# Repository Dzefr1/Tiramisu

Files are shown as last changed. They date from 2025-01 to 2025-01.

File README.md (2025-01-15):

# Tiramisu
Budget and rigid microphone stand costing only around 8$ (cost of plastic) considering you have a donor Tertial lamp.

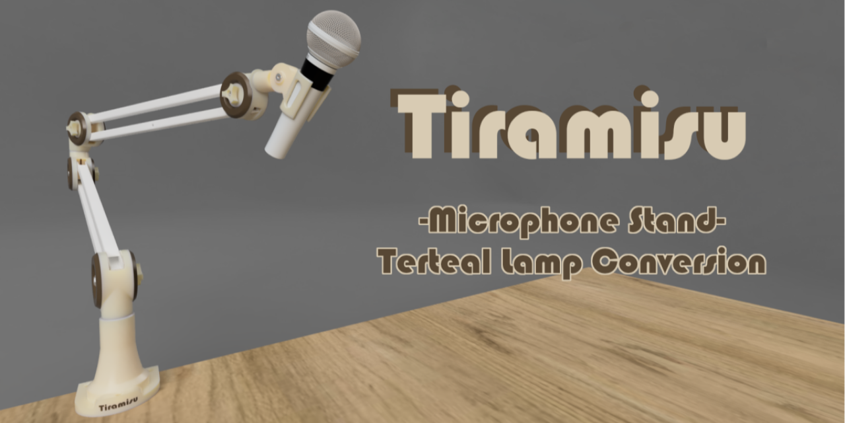
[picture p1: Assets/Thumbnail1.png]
Thumbnail


## Features

Main feature of this design is that it adds two  joints with 360 angle of movement, other also notable features are:
* Larger joint grip area - Additional hole for tightening screw in the middle of the joint, gripping walls of the extrusions more effectively than Tertial's design
* Low amount of materials - Other that filament only additional hardware needed for the conversion are M4 screws (or M4 threaded rod)
* Voron 0 friendly
> Original springs can be used if desired, cap's that hold springs are mountable on tightening screw hole, however additional 35mm M4 rod will be required.

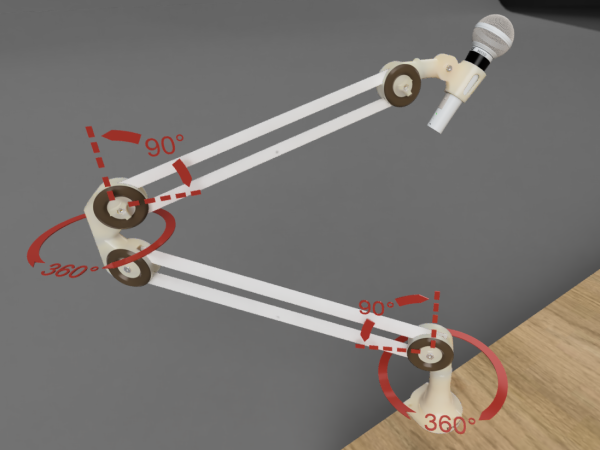
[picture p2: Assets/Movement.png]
movement


## 3D Printing

Most important thing is to **print joints vertically** with 100% infill,
Tested and recommended material is PETG.

### Failures

First few prints of the joints broke after tightening however, part printed vertically was still able to be tightened.
> [!WARNING]  
> If you print with infill less than 100% joints may break when tightening,
> Print settings used on these parts are ABS+ 40% Cubic Infill.
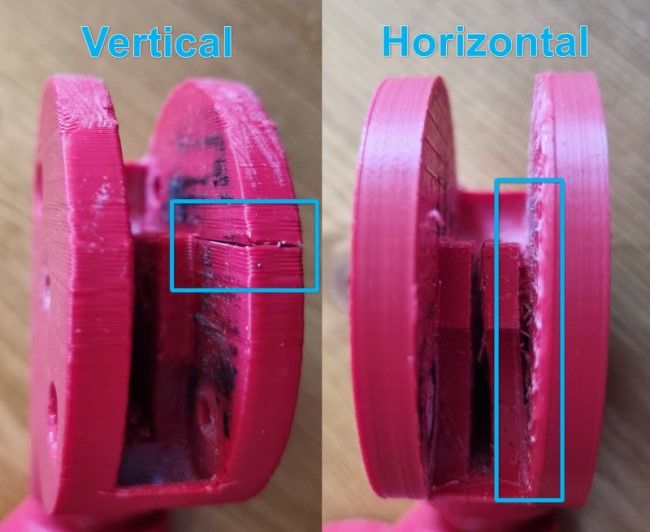
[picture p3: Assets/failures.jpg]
Failures


## Requirements/Part list

* IKEA's Terteal Lamp
* M4 - 28mm Screws x4
* Plastic ~260g (PETG recommended)
* Grease (for rotating joints)

Optional:

* M3 - 8mm or larger (for securing 2nd and 3rd joint)

## Assembly

Build process should be quite self explanatory so I will write down only important notes.

Additional plugs (Plug_Full) should be printed and inserted in extrusions (rods) to make them stiffer,
you can **re-use 4 original cable routing plugs** or print them as well (Plug_Hollow).

Tolerances on joints are TIGHT and that's by design, sanding of round 360 degree joints is required to adjust fit and grease is only used on **1st_Joint** and **3rd_Joint**.

<ins>When assembly is completed all joints need to be tightened to minimize side tilt.<ins>

## Acknowledgments

Inspiration:
* [Rode PSA1](https://rode.com/en-us/accessories/stands-bars/psa1) - Joint Tightening
* [Elgato Wave Mic Arm LP](https://www.elgato.com/us/en/p/wave-mic-arm-lp) - Low Profile

Resources:
* [Parts from Terteal lamp](https://grabcad.com/library/ikea-tertial-2) by: Isabella Grebacken

For rendering:
* [Microphone Holder](https://www.printables.com/model/159430-microphone-holder-for-mic-stand) by: LilMekey
* [Microphone 3D Model](https://grabcad.com/library/shure-microphone-1) by: Keith Moore

## Support 

Like this and want more?

<a href="https://buymeacoffee.com/veljkot6r" target="_blank">Buy Me A Coffee</a>

## License


This work is licensed under CC BY-SA 4.0

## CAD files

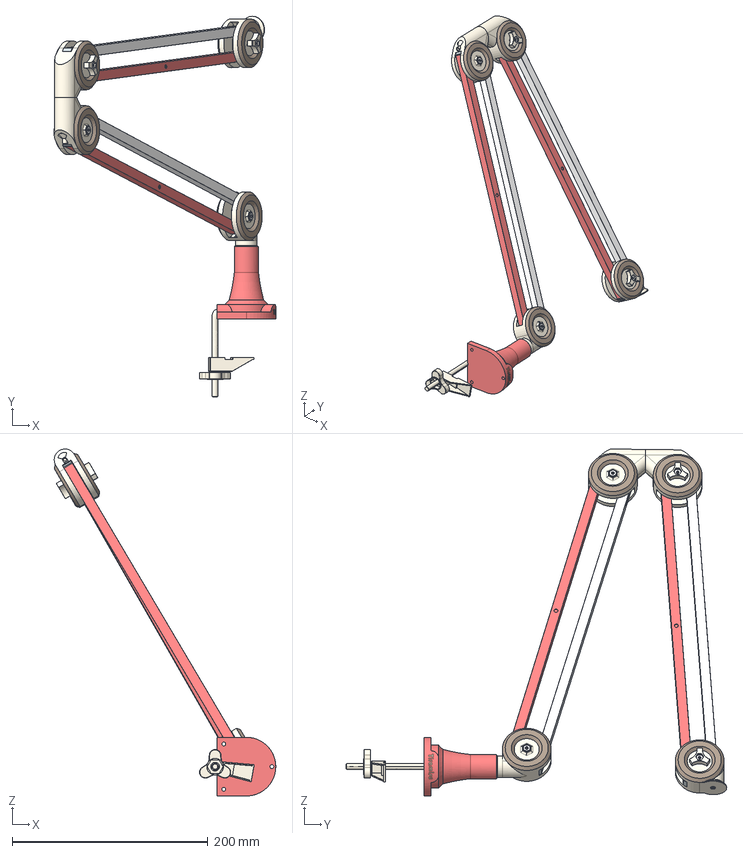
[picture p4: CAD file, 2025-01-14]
3D-Models/Tiramisu_Assembly.step
226.5 x 389.0 x 354.7 mm
1st_Joint
19 Extrusion x 2
19(2) Extrusion x 2
90Deg_2nd_Joint_wSecureScrew
90Deg_3rd_Joint
90Deg_Mic_Mount
28 Base bar
31 Flower knob
30 Security cap
Joint_Cap x 8
24 Triangular knob x 4
14 3mm nut_2_stp x 8
26.2 Cap x 4
26.2 Cap_1 x 4

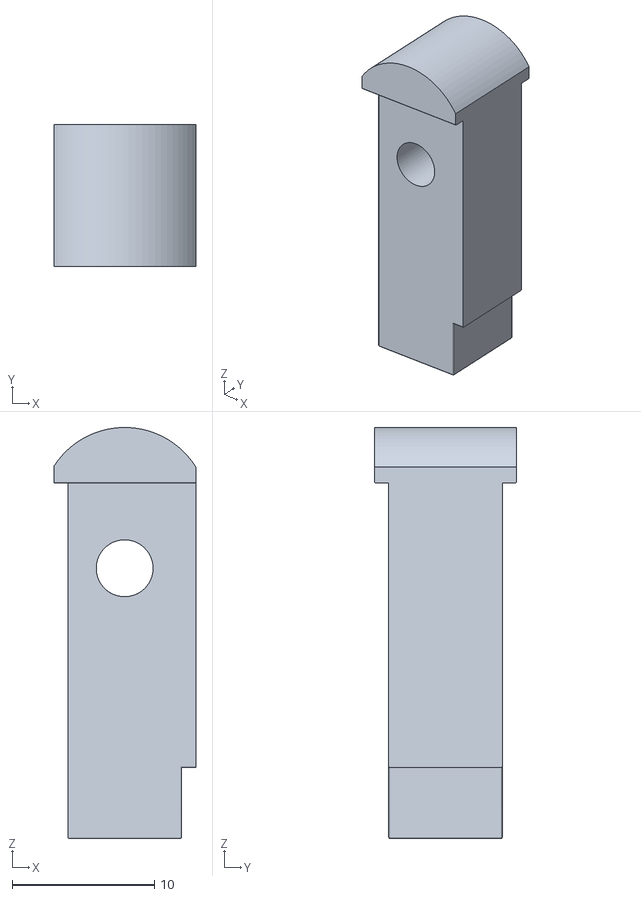
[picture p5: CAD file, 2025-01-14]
3D-Models/Plug_Full.stl
9.95 x 10.0 x 28.9

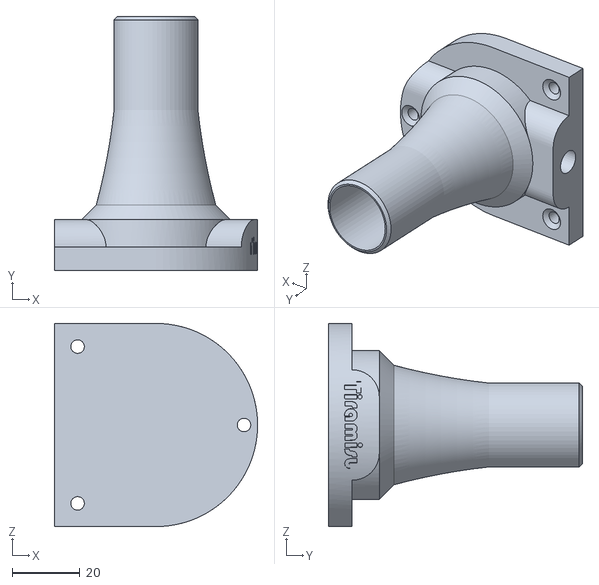
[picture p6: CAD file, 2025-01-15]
3D-Models/Base.stl
60.0 x 75.0 x 60.0

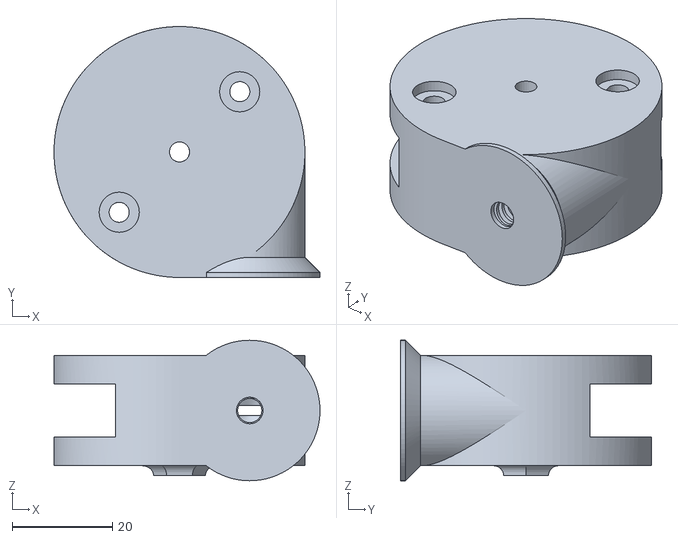
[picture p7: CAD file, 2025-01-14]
3D-Models/Mic_Mount_Variant2.stl
53.0 x 50.0 x 28.0

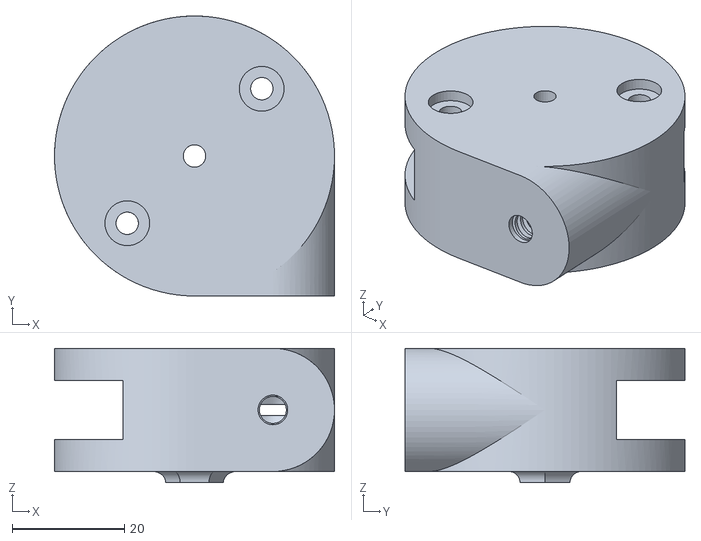
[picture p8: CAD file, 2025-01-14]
3D-Models/Mic_Mount_Variant1.stl
50.0 x 50.0 x 24.0

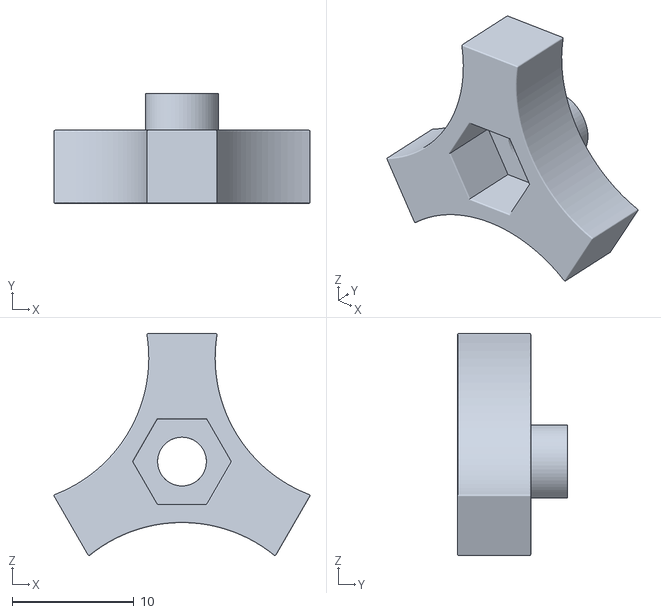
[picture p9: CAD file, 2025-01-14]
3D-Models/Triangular_Knob.stl
21.0 x 9.00 x 18.2

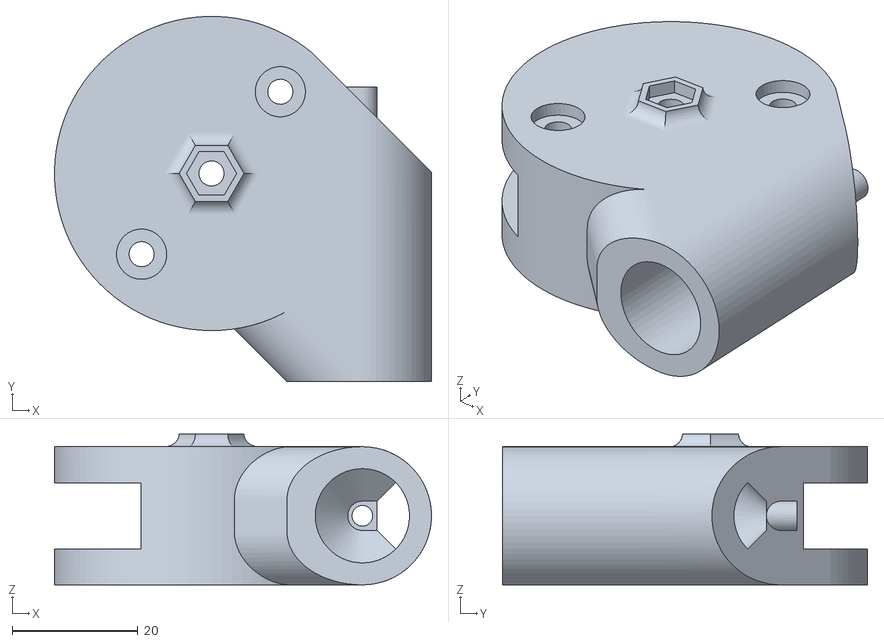
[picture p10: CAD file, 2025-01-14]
3D-Models/2nd_Joint.stl
60.0 x 58.1 x 24.0

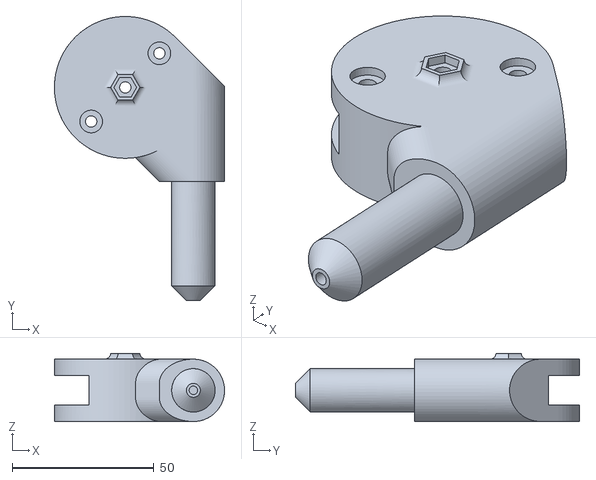
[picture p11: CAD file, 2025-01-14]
3D-Models/3rd_Joint.stl
60.0 x 100.1 x 24.0

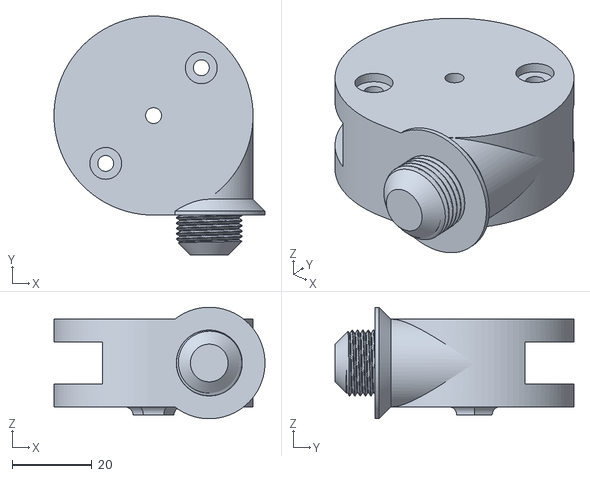
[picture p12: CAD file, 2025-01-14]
3D-Models/Mount_Shure_A25D-Clip.stl
53.0 x 60.0 x 28.0

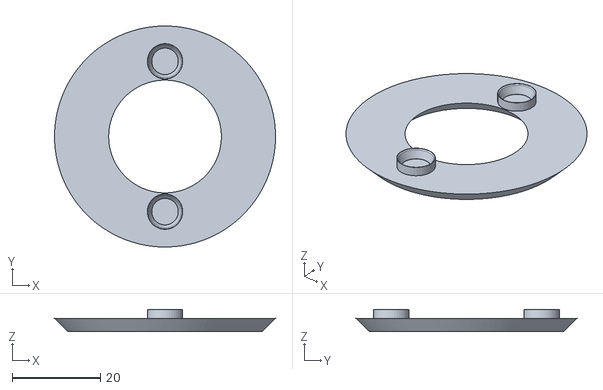
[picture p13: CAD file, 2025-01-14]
3D-Models/Joint_Cap.stl
50.0 x 50.0 x 5.00

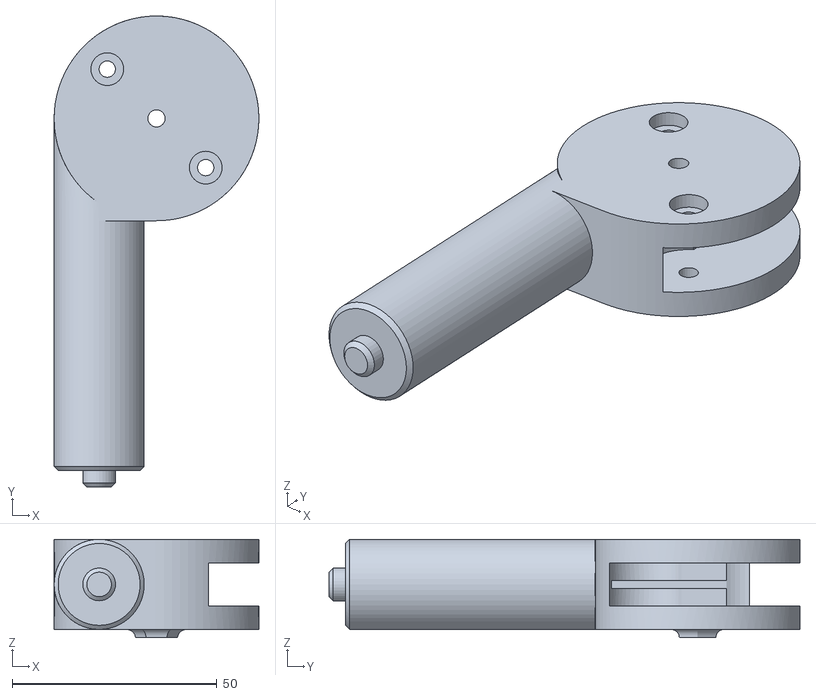
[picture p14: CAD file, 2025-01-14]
3D-Models/1st_Joint.stl
50.0 x 115.0 x 24.0

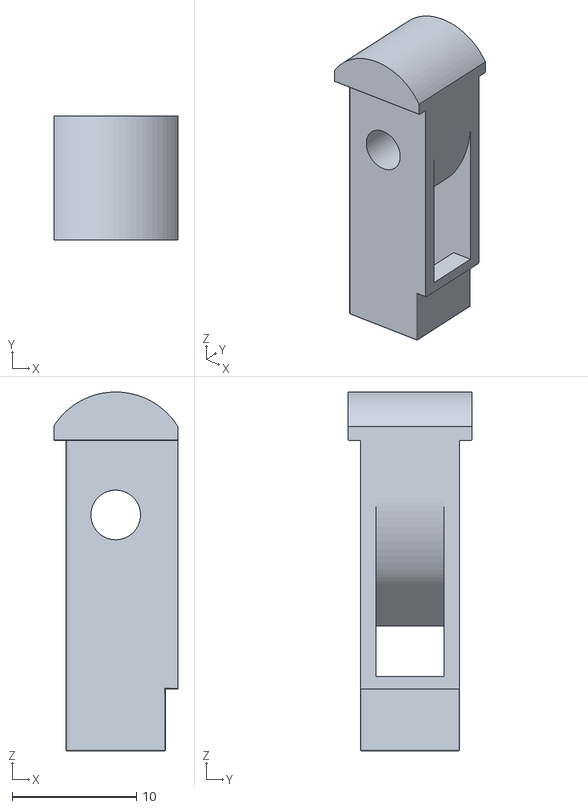
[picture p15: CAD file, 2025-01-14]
3D-Models/Plug_Hollow.stl
9.95 x 10.0 x 28.9

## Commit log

2025-01-14 Initial upload of files
    [1st_Joint.stl, 2nd_Joint.stl, 3rd_Joint.stl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]
2025-01-14 Adding files; adjusting readme
    [Mic_Mount_Variant1.stl, Mic_Mount_Variant2.stl, Plug_Full.stl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]
2025-01-14 Adding step model
    [Tiramisu_Assembly.step]
2025-01-15 Forgot this one
    [Base.stl]
